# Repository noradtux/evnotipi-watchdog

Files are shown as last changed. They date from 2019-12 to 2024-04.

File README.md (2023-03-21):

# Adafruit Trinket M0 watchdog for EVNotiPi
I shared this board on two manufacturers sites:
- https://aisler.net/p/TADOVIMT (shipping from Germany and USA; quicker but more expensive; also can source all parts for assembly by ordering "Precious Parts")
- https://oshpark.com/shared_projects/yOh5dQH3 (shipping from USA; slow)
See hardware/BOM.txt

## Building
You will need PlatformIO for building and installing the firmware. See https://docs.platformio.org/en/latest/installation.html for installation instructions.

To build and upload attach the Trinket M0 by USB and run ```pio run -t upload```.

# Easy adaptor for connecting the watchdog to the Pi
Plugging in patch cables in top of the CAN hat uses lots of space which the case does not provide. So the original solution was to bend the pins to save some verical space. Now there is a simple adaptor board which saves some millimeters and also allows connecting through a 5 pin ribbon cable.

Available here: https://aisler.net/p/ODQEXOXX

I suggest using a 10cm female-female jumper cable with (at least) 5 pins.

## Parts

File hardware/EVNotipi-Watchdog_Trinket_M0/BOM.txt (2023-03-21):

J1,J2: PinSocket 5 pin
J3: 5 pin PinHeader
J4: 2 pin PinHeader
J5: 4 pin PinHeader (optional)
R1: 100K
R2,R3: 27K
Q1: BS170 (N-Channel FET)
Q2: IRF5305 (P-Channel FET)
U1: TSR2-2450 (2A DC-DC converter)
C1: 100nF
D1: Diode 0805 20V 1A

Also: Adafruit Trinket M0

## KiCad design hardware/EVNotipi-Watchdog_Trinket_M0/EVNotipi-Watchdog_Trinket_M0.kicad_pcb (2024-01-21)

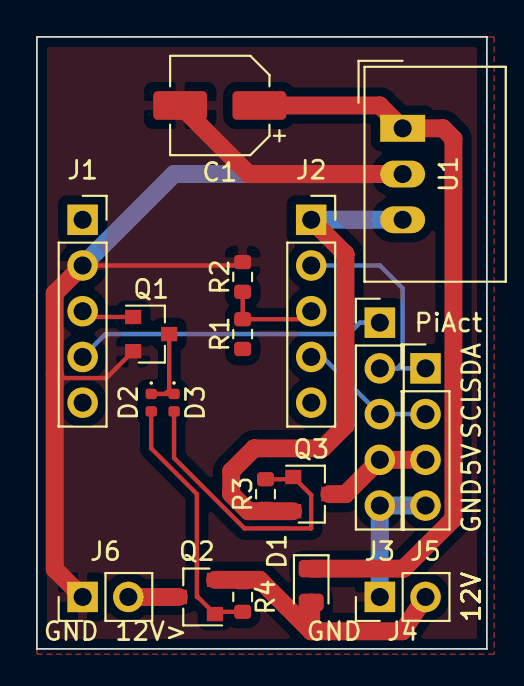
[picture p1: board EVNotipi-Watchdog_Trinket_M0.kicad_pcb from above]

Board: 2 copper layers, 25.0 x 34.0 mm, 18 parts (0 on the bottom side), 14 nets.

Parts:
C1: CP; CP_Elec_5x3
D1: D_Schottky; D_0805_2012Metric
D2, D3: D_Schottky; D_0402_1005Metric
J1: Conn_M0_Left; PinSocket_1x05_P2.54mm_Vertical
J2: Conn_M0_Right; PinSocket_1x05_P2.54mm_Vertical
J3: Conn_Pi; PinHeader_1x05_P2.54mm_Vertical
J4, J6: Conn_Pwr; PinHeader_1x02_P2.54mm_Vertical
J5: Conn_i2c; PinHeader_1x04_P2.54mm_Vertical
Q1: 2N7002; SOT-23
Q2, Q3: IRLML9301; SOT-23
R1: R100K; R_0603_1608Metric
R2, R3, R4: R27K; R_0603_1608Metric
U1: TSR_2-2450; Converter_DCDC_TRACO_TSR-1_THT

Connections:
5V_ENA: J1.3, Q1.1
12V_OUT: J6.2, Q2.3
ADC: J2.3, R1.2, R2.2
GND: C1.2, J1.2, J3.5, J4.1, J5.4, J6.1, Q1.2, R2.1, U1.2
unnamed: C1.1, D1.1, U1.1
unnamed: D2.1, D3.1, Q1.3
unnamed: D2.2, Q2.1, R4.1
unnamed: D3.2, Q3.1, R3.1
Pi_Running: J1.4, J3.1
SCL: J2.4, J3.3, J5.2
SDA: J2.2, J3.2, J5.1
VCC5V: J2.1, Q3.2, R3.2, U1.3
VCC12V: D1.2, J4.2, Q2.2, R1.1, R4.2
VCC_Pi: J3.4, J5.3, Q3.3

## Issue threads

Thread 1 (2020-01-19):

Diode and Capacitor Missing from BOM.txt

DBestman, 2020-01-19:
Values for D1 and C1 are missing from BOM.txt

Jonaswitze, 2022-04-20:
have you figured it out?

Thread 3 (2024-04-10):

problems with building

23Errors, 2024-04-10:
I have a problem with the building process. When I want to upload the code to the board, this error message is printed:

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

noradtux, 2024-04-10:
Looks like an incompatible change in the "Time" library. I did some adjustment, but can't test right now. Please pull and see if it fixes the build.

23Errors, 2024-04-10:
Yes, this fixed the problem thanks.

Closed 2024-04-10.

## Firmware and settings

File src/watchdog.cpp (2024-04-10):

// vim: sw=3 sts=3 expandtab

#include <Arduino.h>
#include <Wire.h>
#include <TimeLib.h>
#include <Adafruit_DotStar.h>

#if defined(ARDUINO_ARCH_SAMD)
 #define PIN_ADC   PIN_A0  // SAMD pin 3
 #define PIN_5VENA PIN_A4  // SAMD pin 7
 #define PIN_PIRUN PIN_A3  // SAMD pin 8
#else
 #error Unsupported hardware
#endif

#define I2C_ADDR  0x8
#define NUMPIXELS 1
#define ON  1
#define OFF 0

Adafruit_DotStar Pixel = Adafruit_DotStar(
  NUMPIXELS, INTERNAL_DS_DATA, INTERNAL_DS_CLK, DOTSTAR_BGR);

uint8_t ShutdownVolt = 208;   // 12.74V
uint8_t StartupVolt  = 210;   // 12.75V
uint8_t EmergencyShutoffVolt = 196; // 11.9V

uint8_t ADCLastVal = 0;
time_t PiWatchdog = 0;
const time_t WatchdogTimeout = 300; // 5 minutes
uint8_t ReadRegister = 0;
uint8_t ShutdownFlag = 0;

void TimerCallback();

void i2c_onRequest() {
   if (PiWatchdog) PiWatchdog = now();

   Serial.print("Received I2C Request (");
   Serial.print(ReadRegister);
   Serial.println(")");

   switch (ReadRegister) {
      case 0x1:
         Wire.write(ADCLastVal);
         break;
      case 0x2:
         Wire.write(ShutdownFlag);
         break;
      case 0x10:
         Wire.write(StartupVolt);
         Wire.write(ShutdownVolt);
         Wire.write(EmergencyShutoffVolt);
         break;
      case 0x11:
         Wire.write(StartupVolt);
         break;
      case 0x12:
         Wire.write(ShutdownVolt);
         break;
      case 0x13:
         Wire.write(EmergencyShutoffVolt);
         break;
   }
}

void i2c_onReceive(int byteCount) {
   if (PiWatchdog) PiWatchdog = now();

   uint8_t byte = Wire.read();
   Serial.print("Received I2C count(");
   Serial.print(byteCount);
   Serial.print(") data(");
   Serial.print(byte);
   Serial.println(")");

   switch (byte) {
      case 0x1:
      case 0x2:
         ReadRegister = byte;
         break;
      case 0x03:
         PiWatchdog = 1;
         break;
      case 0x04:
         PiWatchdog = 0;
         break;
      case 0x10:
      case 0x11:
      case 0x12:
      case 0x13:
         ReadRegister = byte;
         break;
      case 0x20:
         StartupVolt = Wire.read();
         ShutdownVolt = Wire.read();
         EmergencyShutoffVolt = Wire.read();
         break;
      case 0x21:
         StartupVolt = Wire.read();
         Serial.print("Received StartupVolt(");
         Serial.print(StartupVolt);
         Serial.println(")");
         break;
      case 0x22:
         ShutdownVolt = Wire.read();
         Serial.print("Received ShutdownVolt(");
         Serial.print(ShutdownVolt);
         Serial.println(")");
         break;
      case 0x23:
         EmergencyShutoffVolt = Wire.read();
         Serial.print("Received EmergencyShutoffVolt(");
         Serial.print(EmergencyShutoffVolt);
         Serial.println(")");
         break;
   }

   while (Wire.available () > 0)
      Wire.read ();
}

void setup() {
   analogReference(AR_DEFAULT);
   analogReadResolution(8);

   pinMode(PIN_5VENA, OUTPUT);
   pinMode(PIN_LED, OUTPUT);
   pinMode(PIN_PIRUN, INPUT_PULLDOWN);
   pinMode(PIN_ADC, INPUT);

   Serial.begin(115200);

   Wire.begin(I2C_ADDR);
   Wire.onRequest(i2c_onRequest);
   Wire.onReceive(i2c_onReceive);

   Pixel.begin();
   Pixel.show();
   Serial.println("Initialized");
}

void ledToggle() {
   digitalWrite(PIN_LED, digitalRead(PIN_LED) != HIGH);
}
void ledOn() {
   digitalWrite(PIN_LED, HIGH);
}
void ledOff() {
   digitalWrite(PIN_LED, LOW);
}

void shutdownEnable() {
   ShutdownFlag = 1;
}
void shutdownDisable() {
   ShutdownFlag = 0;
}

void setPowerOn() {
   shutdownDisable();
   digitalWrite(PIN_5VENA, HIGH);
}
void setPowerOff() {
   shutdownEnable();
   digitalWrite(PIN_5VENA, LOW);
}

uint8_t getPower() {
   return digitalRead(PIN_5VENA) == HIGH;
}

uint8_t getPiStatus() {
   return digitalRead(PIN_PIRUN) == HIGH;
}

void setColor(unsigned long int color) {
   Pixel.setPixelColor(0, color);
   Pixel.show();
}
void toggleRGB(unsigned long int color) {
   static int toggle = 0;
   toggle = !toggle;
   if (toggle) {
      setColor(color);
   }
   else {
      setColor(0);
   }
}

uint8_t filteredAnalogRead(unsigned char channel) {
   uint16_t samples = 0;
   for (uint8_t i = 0; i < 16; i++) {
      samples += analogRead(channel);
   }
   return samples / 16;
}

int8_t StateCount = 0;
int8_t EmergencyCount = 0;

void loop() {
   if (getPiStatus())
      ledOn();
   else
      ledOff();

   ADCLastVal = filteredAnalogRead(PIN_ADC);
   //Serial.println(ADCLastVal);

   if (PiWatchdog && now() - PiWatchdog > WatchdogTimeout) {
      Serial.println("PiWatchdog timeout triggered! Resetting system");
      setColor(0x7f7f00);
      setPowerOff();
      delay(300);
      setColor(0x00ff00);
      setPowerOn();
   }

   if (ADCLastVal <= EmergencyShutoffVolt) {
      EmergencyCount++;
      if (EmergencyCount > 50) {
         Serial.println("EMERGENCY SHUTDOWN "+String(ADCLastVal));
         setColor(0x7f0000);
         setPowerOff();
         delay(100);
         setColor(0);
         delay(800);
      }
   }
   else if (ADCLastVal > StartupVolt) {
      EmergencyCount = 0;
      if (StateCount > 5) {
         if (getPower() == OFF) {
            Serial.println("Power on Pi "+String(ADCLastVal));
            setColor(0x007f00);
            setPowerOn();
            delay(60000);  // Give Pi time to boot
         }
         else if (getPower() == ON && getPiStatus() == OFF) { // RPi didn't boot, reset setPower
            Serial.println("Reset Pi?");
            delay(5000);
            if (getPower() == ON && getPiStatus() == OFF) {
               // ok, Pi is not just rebooting, trigger restart
               Serial.println("--> yes, restart");
               setColor(0x7f7f00);
               setPowerOff();
               delay(1000);
               setColor(0x007f00);
               setPowerOn();
               delay(60000);  // Give Pi time to boot 
            }
            else
               Serial.println("--> no, move on");
         }
         else {
            //Serial.println("Pi running "+String(ADCLastVal));
            shutdownDisable();
            toggleRGB(0x007f00);
         }
      }
      else {
         if (StateCount < 0) StateCount = 0;
         StateCount++;
         //setColor(0x00a0a0);
      }
   }
   else if (ADCLastVal <= ShutdownVolt) {
      EmergencyCount = 0;
      if (StateCount < -5) {
         if (getPiStatus() == ON) {
            Serial.println("Request shutdown Pi "+String(ADCLastVal));
            shutdownEnable();
            toggleRGB(0x7f7f00);
         }
         else if (getPower() == ON) {
            Serial.println("Power off Pi "+String(ADCLastVal));
            setPowerOff();
            setColor(0);
         }
      }
      else {
         if (StateCount > 0) StateCount = 0;
         StateCount--;
      }
   }
   delay(100);
}

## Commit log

2019-08-20 Try to improve ADC noise
2019-08-20 Power reduction
2019-08-27 port to M0 and Arduino
2019-09-03 improve i2c handling
2019-09-08 modify low voltage feedback
2019-09-08 implement a simple filter to reduce ADC noise
    [watchdog.cpp]
2019-09-18 add hardware design
    [EVNotipi-Watchdog_Trinket_M0.kicad_pcb, EVNotipi-Watchdog_Trinket_M0.sch]
2019-09-24 give the resistors and the TSR2-2450 more space
    [EVNotipi-Watchdog_Trinket_M0.kicad_pcb, EVNotipi-Watchdog_Trinket_M0.sch]
2019-10-01 Move some labels around
    [EVNotipi-Watchdog_Trinket_M0.kicad_pcb]
2019-10-01 Beef up current carrying traces
    [EVNotipi-Watchdog_Trinket_M0.kicad_pcb]
2019-11-01 add BOM
2019-11-01 add M0 to BOM
2019-11-01 mention BOM in README
2019-11-22 add Raspi watchdog adapter
    [EVNotipi-RasPi-Watchdog-Adapter.kicad_pcb, EVNotipi-RasPi-Watchdog-Adapter.sch]
2019-11-22 move Trinket board to seperate directory
    [EVNotipi-Watchdog_Trinket_M0.kicad_pcb, EVNotipi-Watchdog_Trinket_M0.sch]
2019-11-22 Mention adapter board in README
2019-11-22 describe the cable needed
2019-12-25 Add buffer capacitor and a diode for backflow suppression and protection from polarity reversal
    [EVNotipi-Watchdog_Trinket_M0.kicad_pcb, EVNotipi-Watchdog_Trinket_M0.sch]
2019-12-25 Add labels to silk scren
    [EVNotipi-RasPi-Watchdog-Adapter.kicad_pcb]
2020-02-04 fix GND plate
    [EVNotipi-Watchdog_Trinket_M0.kicad_pcb]
2020-04-15 add comments with pin numbers
2021-12-04 Wait 60 sesoncds after power on to allow rasPi to boot fully
2022-05-08 Update BOM.txt
    Add D1
2024-01-21 updates to board
    [EVNotipi-Watchdog_Trinket_M0.kicad_pcb, EVNotipi-Watchdog_Trinket_M0.sch]
2024-01-27 filter small glitches in running indicator
    [watchdog.cpp]
2024-04-10 use and pin current version of Time
